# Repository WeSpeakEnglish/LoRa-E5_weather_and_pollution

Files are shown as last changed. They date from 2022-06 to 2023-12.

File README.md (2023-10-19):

# This PolluTAG based on LoRa E5 mini modules from seed.
It is custom FW, so you need to erase the STM32 chip first [Erase Factory AT Firmware](https://wiki.seeedstudio.com/LoRa_E5_mini/#21-erase-factory-at-firmware), you may need to retrieve and save the Device EUI before erasing of the Factory AT Firmware before we program with SDK

# Sensors for this custom build
1. SHT40 for humidity and temperature over I2C2 
2. ZE27-O3 Ozone sensor over USART2
3. SN-GCJA5 PM sensor over I2C2 

## Whole PRJ is ready to compile in CubeIDE
*LoRa-E5_weather_and_pollution.ioc* is configuration file for CubeMX
*decoder.js* - is decoder for payload for datacake - just copy this JS code into decoder section

### It is sending the payload over LoRaWAN appx. every 2.5 mins
Usually it takes up to 10 min. to react on downlink command (depend of communication stability)

### Downlink port #2
Encoder for downlink (measurements.LED_ON is interface fild on datacake):
```javascript 
function Encoder(measurements, port) {
    if(measurements.LED_ON.value) return [1];
    else return [0];
}
```

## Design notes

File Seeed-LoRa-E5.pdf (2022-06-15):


18/03/2022

Seeed-LoRa-E5 Project
Configuration Report

## 1. Description

### 1.1. Project

Project Name | Seeed-LoRa-E5
Board Name | custom
Generated with: | STM32CubeMX 6.5.0
Date | 03/18/2022

### 1.2. MCU

MCU Series | STM32WL
MCU Line | STM32WLEx
MCU name | STM32WLE5JCIx
MCU Package | UFBGA73
MCU Pin number | 73

### 1.3. Core(s) information

Core(s) | ARM Cortex-M4

## 2. Pinout Configuration

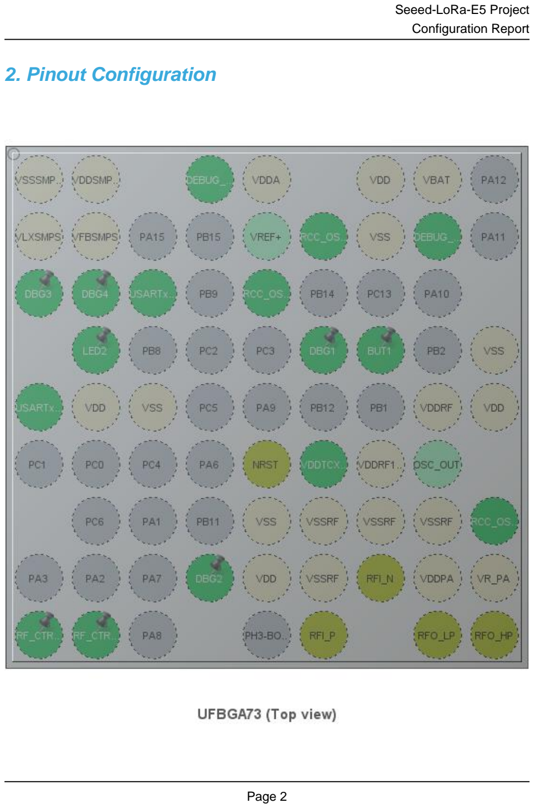
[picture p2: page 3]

## 3. Pins Configuration

Pin Number UFBGA73 | Pin Name (function after reset) | Pin Type | Alternate Function(s) | Label
A1 | VSSSMPS | Power
A2 | VDDSMPS | Power
A4 | PA14 | I/O | DEBUG_JTCK-SWCLK
A5 | VDDA | Power
A7 | VDD | Power
A8 | VBAT | Power
B1 | VLXSMPS | Power
B2 | VFBSMPS | Power
B6 | PC14-OSC32_IN | I/O | RCC_OSC32_IN
B7 | VSS | Power
B8 | PA13 | I/O | DEBUG_JTMS-SWDIO
C1 | PB3 * | I/O | GPIO_Output | DBG3
C2 | PB4 * | I/O | GPIO_Output | DBG4
C3 | PB7 | I/O | USART1_RX | USARTx_RX
C5 | PC15-OSC32_OUT | I/O | RCC_OSC32_OUT
D2 | PB5 * | I/O | GPIO_Output | LED2
D6 | PA0 * | I/O | GPIO_Output | DBG1
D7 | PB13 | I/O | GPIO_EXTI13 | BUT1
D9 | VSS | Power
E1 | PB6 | I/O | USART1_TX | USARTx_TX
E2 | VDD | Power
E3 | VSS | Power
E8 | VDDRF | Power
E9 | VDD | Power
F5 | NRST | Reset
F6 | PB0-VDD_TCXO | I/O | VDDTCXO
F7 | VDDRF1V55 | Power
G5 | VSS | Power
G6 | VSSRF | Power
G7 | VSSRF | Power
G8 | VSSRF | Power
G9 | OSC_IN | MonoIO | RCC_OSC_IN
H4 | PB10 * | I/O | GPIO_Output | DBG2
H5 | VDD | Power
H6 | VSSRF | Power
H7 | RFI_N | MonoIO

Pin Number UFBGA73 | Pin Name (function after reset) | Pin Type | Alternate Function(s) | Label
H8 | VDDPA | Power
H9 | VR_PA | Power
J1 | PA4 * | I/O | GPIO_Output | RF_CTRL1
J2 | PA5 * | I/O | GPIO_Output | RF_CTRL2
J6 | RFI_P | MonoIO
J8 | RFO_LP | MonoIO
J9 | RFO_HP | MonoIO

* The pin is affected with an I/O function

## 4. Clock Tree Configuration

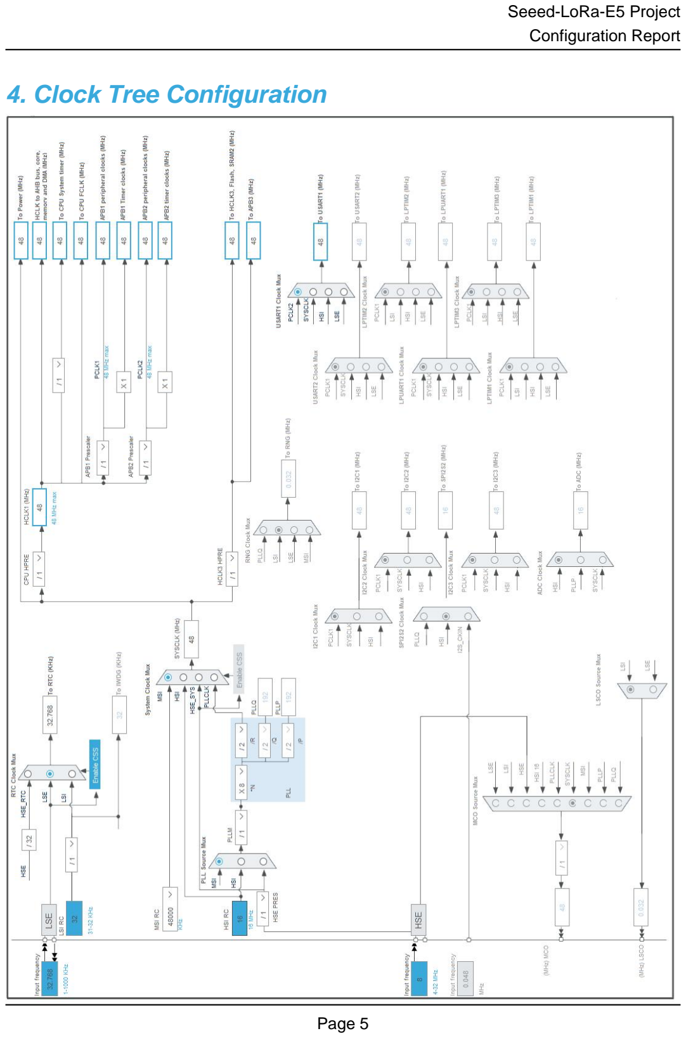
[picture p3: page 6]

## 5. Software Project

### 5.1. Project Settings

Name | Value
Project Name | Seeed-LoRa-E5
Project Folder | C:\Users\danam\STM32CubeIDE\workspace_1.7.0\Seeed-LoRa-E5
Toolchain / IDE | STM32CubeIDE
Firmware Package Name and Version | STM32Cube FW_WL V1.2.0
Application Structure | Advanced
Generate Under Root | Yes
Do not generate the main() | No
Minimum Heap Size | 0x200
Minimum Stack Size | 0x400

### 5.2. Code Generation Settings

Name | Value
STM32Cube MCU packages and embedded software | Copy only the necessary library files
Generate peripheral initialization as a pair of '.c/.h' files | Yes
Backup previously generated files when re-generating | Yes
Keep User Code when re-generating | Yes
Delete previously generated files when not re-generated | Yes
Set all free pins as analog (to optimize the power consumption) | No
Enable Full Assert | No

### 5.3. Advanced Settings - Generated Function Calls

Rank | Function Name | Peripheral Instance Name
1 | SystemClock_Config | RCC
2 | MX_GPIO_Init | GPIO
3 | MX_ADC_Init | ADC
4 | MX_RTC_Init | RTC
5 | MX_DMA_Init | DMA
6 | MX_USART1_UART_Init | USART1
7 | MX_SUBGHZ_Init | SUBGHZ
8 | MX_LoRaWAN_Init | LORAWAN

## 6. Power Consumption Calculator report

### 6.1. Microcontroller Selection

Series | STM32WL
Line | STM32WLEx
MCU | STM32WLE5JCIx
Datasheet | DS13105_Rev7

### 6.2. Parameter Selection

Temperature | 25
Vdd | 3.0

### 6.3. Battery Selection

Battery | Li-SOCL2(AAA700)
Capacity | 700.0 mAh
Self Discharge | 0.08 %/month
Nominal Voltage | 3.6 V
Max Cont Current | 10.0 mA
Max Pulse Current | 30.0 mA
Cells in series | 1
Cells in parallel | 1

### 6.4. Sequence

Step | Step1 | Step2
Mode | RUN | STOP2
Vdd | 3.0 | 3.0
Voltage Source | Battery | Battery
Range | Range1-Medium/SMPS-OFF | NoRange
Fetch Type | SRAM1 | NA
CPU Frequency | 48 MHz | 0 Hz
Clock Configuration | MSI | ALL_CLOCKS_OFF
Clock Source Frequency | 48 MHz | 0 Hz
Peripherals
Additional Cons. | 0 mA | 0 mA
Average Current | 5.65 mA | 885 nA
Duration | 0.1 ms | 0.9 ms
DMIPS | 60.0 | 0.0
Ta Max | 124.47 | 125
Category | In DS Table | In DS Table

### 6.5. Results

Sequence Time | 1 ms | Average Current | 565.8 µA
Battery Life | 1 month, 21 days, 1 hour | Average DMIPS | 60.0 DMIPS

### 6.6. Chart

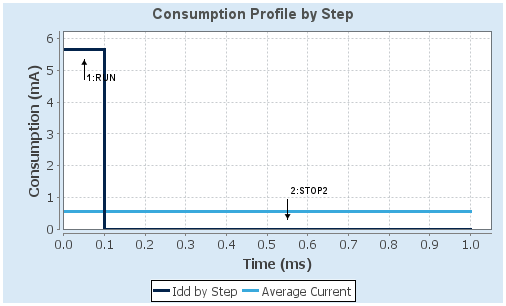
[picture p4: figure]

## 7. Peripherals and Middlewares Configuration

### 7.1. ADC

mode: Temperature Sensor Channel
mode: Vrefint Channel
7.1.1. Parameter Settings:

ADC_Settings:
Clock Prescaler | Synchronous clock mode divided by 4 *
Resolution | ADC 12-bit resolution
Calibration | Disable
Data Alignment | Right alignment
Scan Conversion Mode | Disabled
End Of Conversion Selection | End of single conversion
Low Power Auto Wait | Disabled
Auto Off | Disabled
Continuous Conversion Mode | Disabled
Discontinuous Conversion Mode | Disabled
External Trigger Conversion Source | Regular Conversion launched by software
External Trigger Conversion Edge | None
DMA Continuous Requests | Disabled
Overrun behaviour | Overrun data overwritten *
Sequencer | Sequencer set to fully configurable
SamplingTime Common 1 | 160.5 Cycles *
SamplingTime Common 2 | 160.5 Cycles *
Oversampling Mode | Disabled
Trigger Frequency | High frequency
ADC_Regular_ConversionMode:
Enable Regular Conversions | Disable

### 7.2. ADV_TRACE

mode: Enabled

### 7.3. DEBUG

JTAG and Trace: Serial Wire

### 7.4. MISC

mode: misc

### 7.5. RCC

High Speed Clock (HSE): TCXO
Low Speed Clock (LSE) : Crystal/Ceramic Resonator
7.5.1. Parameter Settings:

System Parameters:

VDD voltage (V) | 3.3
Instruction Cache | Enabled
Prefetch Buffer | Disabled
Data Cache | Enabled
Flash Latency(WS) | 2 WS (3 CPU cycle)
RCC Parameters:
HSI Calibration Value | 64
MSI Calibration Value | 0
MSI Auto Calibration | Enabled
HSE Startup Timout Value (ms) | 100
LSE Startup Timout Value (ms) | 5000
LSE Drive Capability | LSE oscillator low drive capability
Power Parameters:
Power Regulator Voltage Scale | Power Regulator Voltage Scale 1

### 7.6. RTC

mode: Activate Clock Source
mode: Activate Calendar
Alarm A: Internal Alarm A
7.6.1. Parameter Settings:

General:

Asynchronous Predivider value | RTC_PREDIV_A *
Bin Mode | Free running Binary mode *
SSRU Underflow Interrupt | Enabled
Alarm A:
Free running 32 bit value | 0
Binary AutoControl | RTC_ALARMSUBSECONDBIN_AUTOCLR_NO *
Free running 32 bit mask | SS[31:0] are compared and must match to activate alarm.

### 7.7. SEQUENCER

mode: Enabled

### 7.8. SUBGHZ

mode: Activated
7.8.1. Parameter Settings:
Baudrate Prescaler Value | 4 *

### 7.9. SYS

Timebase Source: None

### 7.10. TIMER

mode: Enabled

### 7.11. TINY_LPM

mode: Enabled

### 7.12. USART1

Mode: Asynchronous
7.12.1. Parameter Settings:

Basic Parameters:

Baud Rate | 115200
Word Length | 8 Bits (including Parity)
Parity | None
Stop Bits | 1
Advanced Parameters:
Data Direction | Receive and Transmit
Over Sampling | 16 Samples
Single Sample | Disable
ClockPrescaler | 1
Fifo Mode | Enable *
Txfifo Threshold | 1 eighth full configuration

Rxfifo Threshold | 1 eighth full configuration
Advanced Features:
Auto Baudrate | Disable
TX Pin Active Level Inversion | Disable
RX Pin Active Level Inversion | Disable
Data Inversion | Disable
TX and RX Pins Swapping | Disable
Overrun | Enable
DMA on RX Error | Enable
MSB First | Disable

### 7.13. LORAWAN

mode: Enabled
7.13.1. LoRaWAN application:

Application selection:
Application | End Node skeleton *
Application configuration recommandations | !! Please read carefully Information panel below!!

board settings:

Send Tx on Timer or Button Evt | TX_ON_TIMER
Probes Lines in Platform Settings | true *
lora_app:
Active region | LORAMAC_REGION_US915 *
Transmition duty cycle | 10000
Application user port | 2
Switch class port | 3
Default class | CLASS_A
Default handler message state | Unconfirmed message
Handler Adaptive Data Rate | On
Default activation type | OTAA
Force rejoin at each reboot | true
Default Unicast ping slots periodicity | 4
Default reponse timeout for class b and class c confirmed downlink frames in milli seconds. | 8000
sys_conf:
Trace verbose level | VLEVEL_M
Enable Application Logging | true
Disable Low Power Mode | false
Enable Sensor | false

7.13.2. LoRaWAN commissioning:

Commissioning:

Public network | true
Current network ID | 0
se-identity:
Static Device EUI | true *
LoRaWAN device EUI | 2C, F7, F1, 20, 24, 90, 0E, A5 *
App/Join EUI | 01, 01, 01, 01, 01, 01, 01, 01
Application key | 8B,0C,9A,82,E6,74,A5,11,B9,E 5,26,A9,11,87,EB,84 *
Network key | 8B,0C,9A,82,E6,74,A5,11,B9,E 5,26,A9,11,87,EB,84 *
Static Device Address | false
Network session key | 2B,7E,15,16,28,AE,D2,A6,AB,F7,15,88,0 9,CF,4F,3C
Application session key | 2B,7E,15,16,28,AE,D2,A6,AB,F7,15,88,0 9,CF,4F,3C

lorawan_conf:

Enable Key read access | true
7.13.3. LoRaWAN middleware:

lorawan_conf:

Region(s) selection | please select the desired region(s) in the list below
Region Asia freq: 923 | false
Region Australia freq: 915 | false
Region China freq: 470 | false
Region China freq: 779 | false
Region Europe freq: 433 | false
Region Europe freq: 868 | true
Region Korea freq: 920 | false
Region India freq: 865 | false
Region USA freq: 915 | true
Region Russia freq: 864 | false
Enable Hybrid mode | true *
Enable LoRaMAC ClassB | false
Enable the context management storage | false
Select the LoRaWAN Link Layer specification version | v1.0.3

radio_conf:

Radio maximum wakeup time (in ms) | 1
radio_board_if:
Select radio Driver | Bsp via extSettings *
mw_log_conf:
Enable Middleware log | true
7.13.4. Platform Settings:
ADC | ADC
RTC | RTC
USART | USART1
Debug Line 1 | PA0
Debug Line 2 | PB10
Debug Line 3 | PB3
Debug Line 4 | PB4

* User modified value

## 8. System Configuration

### 8.1. GPIO configuration

IP | Pin | Signal | GPIO mode | GPIO pull/up pull down | Max Speed | User Label
DEBUG | PA14 | DEBUG_JTCK-SWCLK | n/a | n/a | n/a
| PA13 | DEBUG_JTMS-SWDIO | n/a | n/a | n/a
RCC | PC14-OSC32_IN | RCC_OSC32_IN | n/a | n/a | n/a
| PC15-OSC32_OU T | RCC_OSC32_O UT | n/a | n/a | n/a
| PB0-VDD_TCXO | VDDTCXO | n/a | n/a | n/a
| OSC_IN | RCC_OSC_IN | n/a | n/a | n/a
USART1 | PB7 | USART1_RX | Alternate Function Push Pull | No pull-up and no pull-down | Very High * | USARTx_RX
| PB6 | USART1_TX | Alternate Function Push Pull | No pull-up and no pull-down | Very High * | USARTx_TX
| | | | | * | DBG3
| PB4 | GPIO_Output | Output Push Pull | No pull-up and no pull-down | Very High * | DBG4
| PB5 | GPIO_Output | Output Push Pull | No pull-up and no pull-down | Very High * | LED2
| PA0 | GPIO_Output | Output Push Pull | No pull-up and no pull-down | Very High * | DBG1
| PB13 | GPIO_EXTI13 | External Interrupt Mode with Falling edge trigger detection | Pull-up * | n/a | BUT1
| PB10 | GPIO_Output | Output Push Pull | No pull-up and no pull-down | Very High * | DBG2
| PA4 | GPIO_Output | Output Push Pull | No pull-up and no pull-down | Very High * | RF_CTRL1
| PA5 | GPIO_Output | Output Push Pull | No pull-up and no pull-down | Very High * | RF_CTRL2
GPIO | PB3 | GPIO_Output | Output Push Pull | No pull-up and no pull-down | Very High

### 8.2. DMA configuration

DMA request | Stream | Direction | Priority
USART1_TX | DMA1_Channel1 | Memory To Peripheral | Low

USART1_TX: DMA1_Channel1 DMA request Settings:

Mode: | Normal
Peripheral Increment: | Disable
Memory Increment: | Enable *
Peripheral Data Width: | Byte
Memory Data Width: | Byte

### 8.3. NVIC configuration

8.3.1. NVIC
Interrupt Table | Enable | Preenmption Priority | SubPriority
Non maskable interrupt | true | 0 | 0
Hard fault interrupt | true | 0 | 0
Memory management fault | true | 0 | 0
Prefetch fault, memory access fault | true | 0 | 0
Undefined instruction or illegal state | true | 0 | 0
System service call via SWI instruction | true | 0 | 0
Debug monitor | true | 0 | 0
Pendable request for system service | true | 0 | 0
System tick timer | true | 0 | 0
RTC Tamper, RTC TimeStamp, LSECSS and RTC SSRU Interrupts | true | 0 | 0
DMA1 Channel 1 Interrupt | true | 2 | 0
USART1 Interrupt | true | 2 | 0
EXTI Lines [15:10] Interrupt | true | 0 | 0
RTC Alarms (A and B) Interrupt | true | 0 | 0
SUBGHZ Radio Interrupt | true | 0 | 0
PVD and PVM detector | | unused
FLASH (CFI) global Interrupt | | unused
RCC Interrupt | | unused
ADC Interrupt | | unused
8.3.2. NVIC Code generation

Enabled interrupt Table Select for init sequence ordering

| | Generate IRQ
| | handler | Call HAL handler
Non maskable interrupt | false | true | false
Hard fault interrupt | false | true | false
Memory management fault | false | true | false
Prefetch fault, memory access fault | false | true | false
Undefined instruction or illegal state | false | true | false
System service call via SWI instruction | false | true | false
Debug monitor | false | true | false
Pendable request for system service | false | true | false
System tick timer | false | true | false
RTC Tamper, RTC TimeStamp, LSECSS and RTC SSRU Interrupts | false | true | true
DMA1 Channel 1 Interrupt | false | true | true
USART1 Interrupt | false | true | true

Enabled interrupt Table | Select for init sequence ordering | Generate IRQ handler | Call HAL handler
EXTI Lines [15:10] Interrupt | false | true | true
RTC Alarms (A and B) Interrupt | false | true | true
SUBGHZ Radio Interrupt | false | true | true

* User modified value

## 9. System Views

9.1. Category view
9.1.1. Current

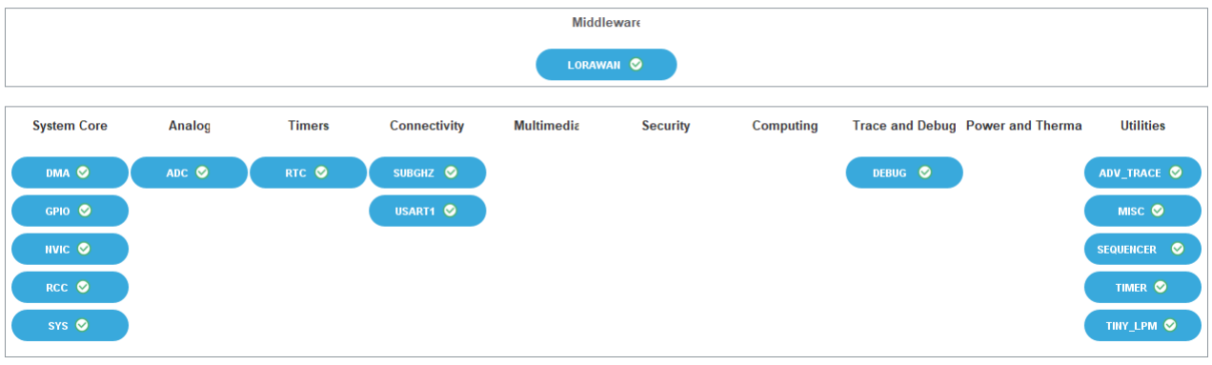
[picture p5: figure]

## 10. Docs & Resources

Type | Link
Presentations | https://www.st.com/resource/en/product_presentation/stm32-stm8_embedded_software_solutions.pdf
Presentations | https://www.st.com/resource/en/product_presentation/stm32_eval-tools_portfolio.pdf
Presentations | https://www.st.com/resource/en/product_presentation/stm32_stm8_functi onal-safety-packages.pdf
Presentations | https://www.st.com/resource/en/product_presentation/stm32-stm8_software_development_tools.pdf
Presentations | https://www.st.com/resource/en/product_presentation/microcontrollers_stm32wl_series_product_overview.pdf
Presentations | https://www.st.com/resource/en/product_presentation/stm32cubemonitor-wireless-longrange_rftest.pdf
Flyers | https://www.st.com/resource/en/flyer/flnucleolrwan.pdf
Flyers | https://www.st.com/resource/en/flyer/flstm32nucleo.pdf
Flyers | https://www.st.com/resource/en/flyer/flstm32wl.pdf
Flyers | https://www.st.com/resource/en/flyer/flstm32wbvl.pdf
Application Notes | https://www.st.com/resource/en/application_note/an1181-electrostatic-discharge-sensitivity-measurement-stmicroelectronics.pdf
Application Notes | https://www.st.com/resource/en/application_note/an1709-emc-design-guide-for-stm8-stm32-and-legacy-mcus-stmicroelectronics.pdf
Application Notes | https://www.st.com/resource/en/application_note/an2606-stm32-microcontroller-system-memory-boot-mode-stmicroelectronics.pdf
Application Notes | https://www.st.com/resource/en/application_note/an2639-soldering-recommendations-and-package-information-for-leadfree-ecopack-mcus-and-mpus-stmicroelectronics.pdf
Application Notes | https://www.st.com/resource/en/application_note/an2834-how-to-get-the-best-adc-accuracy-in-stm32-microcontrollers-stmicroelectronics.pdf
Application Notes | https://www.st.com/resource/en/application_note/an2867-oscillator-design-guide-for-stm8afals-stm32-mcus-and-mpus-stmicroelectronics.pdf

Application Notes | https://www.st.com/resource/en/application_note/an3126-audio-and-waveform-generation-using-the-dac-in-stm32-products-stmicroelectronics.pdf
Application Notes | https://www.st.com/resource/en/application_note/an3155-usart-protocol-used-in-the-stm32-bootloader-stmicroelectronics.pdf
Application Notes | https://www.st.com/resource/en/application_note/an4013-stm32-crossseries-timer-overview-stmicroelectronics.pdf
Application Notes | https://www.st.com/resource/en/application_note/an4229-how-to-implement-a-vocoder-solution-using-stm32-microcontrollers-stmicroelectronics.pdf
Application Notes | https://www.st.com/resource/en/application_note/an4286-spi-protocol-used-in-the-stm32-bootloader-stmicroelectronics.pdf
Application Notes | https://www.st.com/resource/en/application_note/an4655-virtually-increasing-the-number-of-serial-communication-peripherals-in-stm32-applications-stmicroelectronics.p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
Application Notes | https://www.st.com/resource/en/application_note/an4750-handling-of-soft-errors-in-stm32-applications-stmicroelectronics.pdf
Application Notes | https://www.st.com/resource/en/application_note/an4759-using-the-hardware-realtime-clock-rtc-and-the-tamper-management-unit-tamp-with-stm32-microcontrollers-stmicroe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
Application Notes | https://www.st.com/resource/en/application_note/an4776-generalpurpose-timer-cookbook-for-stm32-microcontrollers-stmicroelectronics.pdf
Application Notes | https://www.st.com/resource/en/application_note/an4803-highspeed-si-simulations-using-ibis-and-boardlevel-simulations-using-hyperlynx-si-on-stm32-mcus-and-mpus-stmic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
Application Notes | https://www.st.com/resource/en/application_note/an4894-eeprom-emulation-techniques-and-software-for-stm32-microcontrollers-stmicroelectronics.pdf
Application Notes | https://www.st.com/resource/en/application_note/an5027-interfacing-pdm-digital-microphones-using-stm32-mcus-and-mpus-stmicroelectronics.pdf
Application Notes | https://www.st.com/resource/en/application_note/an5036-thermal-management-guidelines-for-stm32-applications-stmicroelectronics.pdf
Application Notes | https://www.st.com/resource/en/application_note/an5042-precise-hse-

| frequency-and-startup-time-tuning-for-stm32-wireless-mcus-stmicroelectronics.pdf
Application Notes | https://www.st.com/resource/en/application_note/an5156-introduction-to-stm32-microcontrollers-security-stmicroelectronics.pdf
Application Notes | https://www.st.com/resource/en/application_note/an5225-usb-typec-power-delivery-using-stm32-mcus-and-mpus-stmicroelectronics.pdf
Application Notes | https://www.st.com/resource/en/application_note/an5406-how-to-build-a-lora-application-with-stm32cubewl-stmicroelectronics.pdf
Application Notes | https://www.st.com/resource/en/application_note/an5407-optimized-rf-board-layout-for-stm32wl-series-stmicroelectronics.pdf
Application Notes | https://www.st.com/resource/en/application_note/an5408-migrating-from-stm32l0-stm32l1-and-stm32l4-series-associated-with-sx12xx-transceivers-to-stm32wl-series-microc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
Application Notes | https://www.st.com/resource/en/application_note/an5409-stm32cube-mcu-package-examples-for-stm32wl-series-stmicroelectronics.pdf
Application Notes | https://www.st.com/resource/en/application_note/an5457-rf-matching-network-design-guide-for-stm32wl-series-stmicroelectronics.pdf
Application Notes | https://www.st.com/resource/en/application_note/an5480-how-to-build-a-sigfox-application-with-stm32cubewl-stmicroelectronics.pdf
Application Notes | https://www.st.com/resource/en/application_note/an5543-enhanced-methods-to-handle-spi-communication-on-stm32-devices-stmicroelectronics.pdf
Application Notes | https://www.st.com/resource/en/application_note/an5568-ultralowpower-features-of-stm32wl-series-microcontrollers-stmicroelectronics.pdf
Application Notes | https://www.st.com/resource/en/application_note/an4899-stm32-microcontroller-gpio-configuration-for-hardware-settings-and-lowpower-consumption-stmicroelectronics.pdf
Application Notes | https://www.st.com/resource/en/application_note/an5690-vrefbuf-peripheral-applications-and-trimming-technique-stmicroelectronics.pdf
Application Notes | https://www.st.com/resource/en/application_note/an5664-rssi-and-snr-for-lora-modulation-on-stm32wl-series-stmicroelectronics.pdf

Application Notes
for related Tools

https://www.st.com/resource/en/application_note/an1202_freertos_guidefreertos-guide-stmicroelectronics.pdf

& Software
Application Notes for related Tools & Software | https://www.st.com/resource/en/application_note/an1602_semihosting_in_truestudio-how-to-do-semihosting-in-truestudio-stmicroelectronics.pdf
Application Notes for related Tools & Software | https://www.st.com/resource/en/application_note/an1801_stm32cubeprogrammer_in_truestudio-installing-stm32cubeprogrammer-in-truestudio-stmicroelectronics.pdf
Application Notes for related Tools & Software | https://www.st.com/resource/en/application_note/atollic_editing_keyboard_shortcuts-atollic-editing-keyboard-shortcuts-stmicroelectronics.pdf
Application Notes for related Tools & Software | https://www.st.com/resource/en/application_note/iar_to_atollic_truestudio_migration_guide-truestudio-for-arm-migration-guide-iar-embedded-workbench-to-truestudio-stm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
Application Notes for related Tools & Software | https://www.st.com/resource/en/application_note/stm32cubemx_installation_in_truestudio-stm32cubemx-installation-in-truestudio-stmicroelectronics.pdf
Application Notes for related Tools & Software | https://www.st.com/resource/en/application_note/an4502-stm32-smbuspmbus-embedded-software-expansion-for-stm32cube-stmicroelectronics.pdf
Application Notes for related Tools & Software | https://www.st.com/resource/en/application_note/an4657-stm32-inapplication-programming-iap-using-the-usart-stmicroelectronics.pdf
Application Notes for related Tools & Software | https://www.st.com/resource/en/application_note/an4759-using-the-hardware-realtime-clock-rtc-and-the-tamper-management-unit-tamp-with-stm32-microcontrollers-stmicroe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
Application Notes for related Tools & Software | https://www.st.com/resource/en/application_note/an4841-digital-signal-processing-for-stm32-microcontrollers-using-cmsis-stmicroelectronics.pdf
Application Notes for related Tools & Software | https://www.st.com/resource/en/application_note/an4894-eeprom-emulation-techniques-and-software-for-stm32-microcontrollers-stmicroelectronics.pdf
Application Notes for related Tools & Software | https://www.st.com/resource/en/application_note/an5042-precise-hse-frequency-and-startup-time-tuning-for-stm32-wireless-mcus-stmicroelectronics.pdf

Application Notes for related Tools & Software | https://www.st.com/resource/en/application_note/an5054-secure-programming-using-stm32cubeprogrammer-stmicroelectronics.pdf
Application Notes for related Tools & Software | https://www.st.com/resource/en/application_note/an5360-getting-started-with-projects-based-on-the-stm32mp1-series-in-stm32cubeide-stmicroelectronics.pdf
Application Notes for related Tools & Software | https://www.st.com/resource/en/application_note/an5361-getting-started-with-projects-based-on-dualcore-stm32h7-microcontrollers-in-stm32cubeide-stmicroelectronics.pd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
Application Notes for related Tools & Software | https://www.st.com/resource/en/application_note/an5394-getting-started-with-projects-based-on-the-stm32l5-series-in-stm32cubeide-stmicroelectronics.pdf
Application Notes for related Tools & Software | https://www.st.com/resource/en/application_note/an5406-how-to-build-a-lora-application-with-stm32cubewl-stmicroelectronics.pdf
Application Notes for related Tools & Software | https://www.st.com/resource/en/application_note/an5409-stm32cube-mcu-package-examples-for-stm32wl-series-stmicroelectronics.pdf
Application Notes for related Tools & Software | https://www.st.com/resource/en/application_note/an5418-how-to-build-a-simple-usbpd-sink-application-with-stm32cubemx-stmicroelectronics.pdf
Application Notes for related Tools & Software | https://www.st.com/resource/en/application_note/an5426-migrating-graphics-middleware-projects-from-stm32cubemx-540-to-stm32cubemx-550-stmicroelectronics.pdf
Application Notes for related Tools & Software | https://www.st.com/resource/en/application_note/an5480-how-to-build-a-sigfox-application-with-stm32cubewl-stmicroelectronics.pdf
Application Notes for related Tools & Software | https://www.st.com/resource/en/application_note/an5481-lorawan-at-commands-for-stm32cubewl-stmicroelectronics.pdf
Application Notes for related Tools & Software | https://www.st.com/resource/en/application_note/an5544-integration-guide-of-sbsfu-on-stm32cubewl-including-kms-stmicroelectronics.pdf
Application Notes | https://www.st.com/resource/en/application_note/an5554-lorawan-

for related Tools & Software | firmware-update-over-the-air-with-stm32cubewl-stmicroelectronics.pdf
Application Notes for related Tools & Software | https://www.st.com/resource/en/application_note/an5564-getting-started-with-projects-based-on-dualcore-stm32wl-microcontrollers-in-stm32cubeide-stmicroelectronics.pd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
Application Notes for related Tools & Software | https://www.st.com/resource/en/application_note/an5566-rf-certification-process-for-nucleowl55jc-stmicroelectronics.pdf
Application Notes for related Tools & Software | https://www.st.com/resource/en/application_note/an5682-how-to-secure-lorawan-and-sigfox-with-stm32cubewl-stmicroelectronics.pdf
Application Notes for related Tools & Software | https://www.st.com/resource/en/application_note/an5687-longpacket-operation-with-stm32cubewl-stmicroelectronics.pdf
Application Notes for related Tools & Software | https://www.st.com/resource/en/application_note/an5731-stm32cubemx-and-stm32cubeide-threadsafe-solution-stmicroelectronics.pdf
Errata Sheets | https://www.st.com/resource/en/errata_sheet/es0506-stm32wle5xx-stm32wle4xx-device-errata-stmicroelectronics.pdf
Datasheet | https://www.st.com/resource/en/datasheet/dm00648230.pdf
Programming Manuals | https://www.st.com/resource/en/programming_manual/pm0214-stm32-cortexm4-mcus-and-mpus-programming-manual-stmicroelectronics.pdf
Programming Manuals | https://www.st.com/resource/en/programming_manual/pm0223-cortexm0-programming-manual-for-stm32l0-stm32g0-stm32wl-and-stm32wb-series-stmicroelectronics.pdf
Reference Manuals | https://www.st.com/resource/en/reference_manual/rm0461-stm32wlex-advanced-armbased-32bit-mcus-with-subghz-radio-solution-stmicroelectronics.pdf
Technical Notes & Articles | https://www.st.com/resource/en/technical_note/tn1163-description-of-wlcsp-for-microcontrollers-and-recommendations-for-its-use-stmicroelectronics.pdf
Technical Notes & Articles | https://www.st.com/resource/en/technical_note/tn1204-tape-and-reel-shipping-media-for-stm32-microcontrollers-in-bga-packages-stmicroelectronics.pdf

Technical Notes & Articles | https://www.st.com/resource/en/technical_note/tn1205-tape-and-reel-shipping-media-for-stm8-and-stm32-microcontrollers-in-fpn-packages-stmicroelectronics.pdf
Technical Notes & Articles | https://www.st.com/resource/en/technical_note/tn1206-tape-and-reel-shipping-media-for-stm8-and-stm32-microcontrollers-in-qfp-packages-stmicroelectronics.pdf
Technical Notes & Articles | https://www.st.com/resource/en/technical_note/tn1207-tape-and-reel-shipping-media-for-stm8-and-stm32-microcontrollers-in-so-packages-stmicroelectronics.pdf
Technical Notes & Articles | https://www.st.com/resource/en/technical_note/tn1208-tape-and-reel-shipping-media-for-stm8-and-stm32-microcontrollers-in-tssop-and-ssop-packages-stmicroelectronics.p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

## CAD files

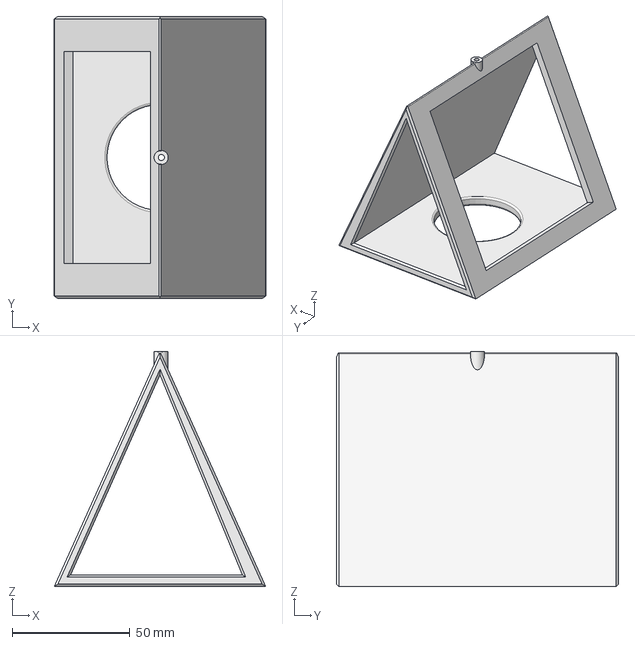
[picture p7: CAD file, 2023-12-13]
CASE_FREECAD/eternal.FCStd
90.0 x 120.0 x 100.0 mm

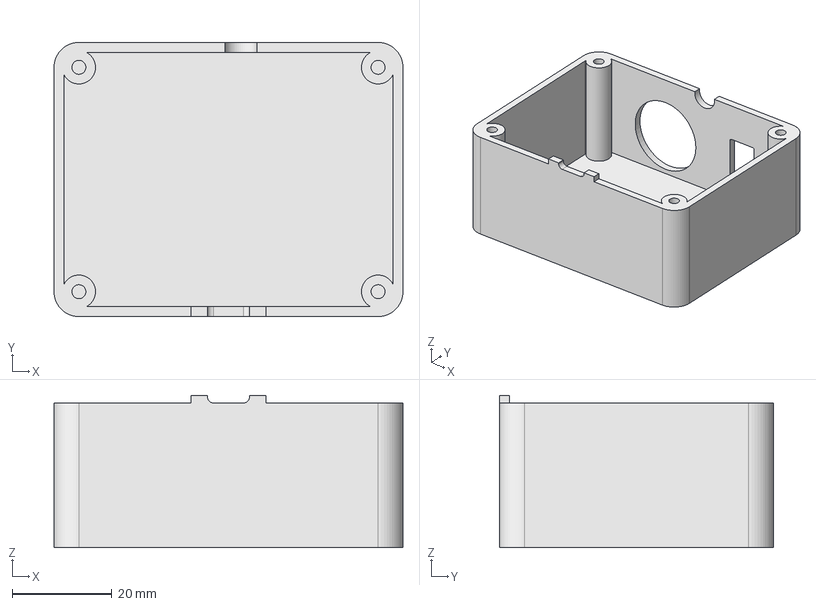
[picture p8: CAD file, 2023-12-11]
CASE_FREECAD/case.FCStd
70.0 x 55.0 x 30.5 mm

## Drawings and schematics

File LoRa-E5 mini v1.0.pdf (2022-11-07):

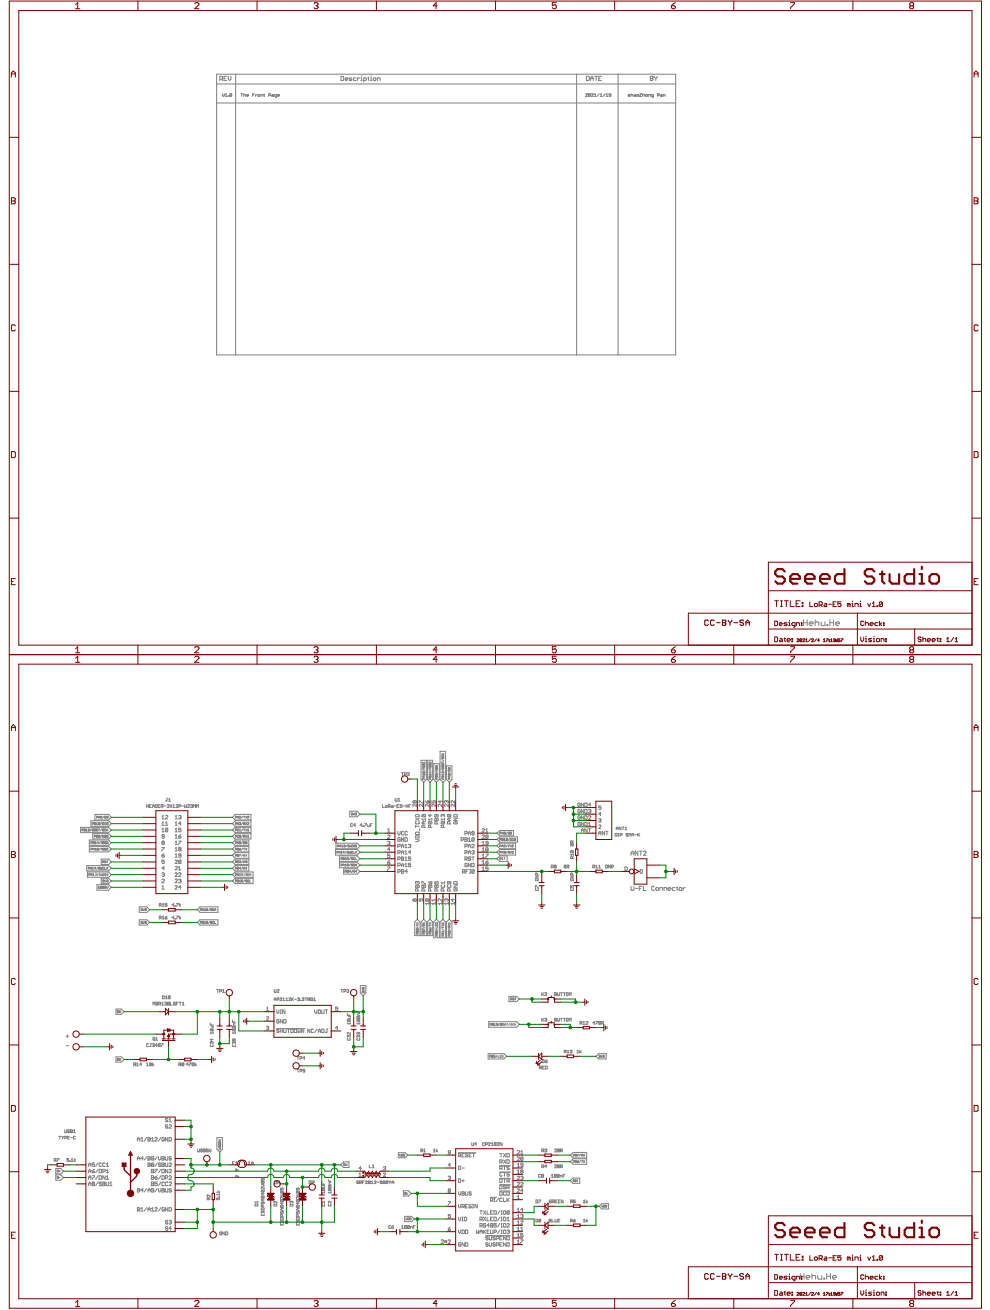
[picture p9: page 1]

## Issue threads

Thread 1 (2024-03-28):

NO DOWLINK ON THE SENSOR with ADR=On when DR is not SF12

pierre-microlide, 2024-03-28:
Hi,
i use Wio-E5 mini board with LoraWan app. All is ok with my gateway to join or read datas from sensor.
But, if i use the ADR=On to save power, when SF is less than 12, downlink are not received by the sensor ? The downlink is sent by the gateway.
I don't understand why ? Please, can you help me ?
Thanks
Regards
Pierre

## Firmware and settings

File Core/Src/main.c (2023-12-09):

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
/* Includes ------------------------------------------------------------------*/
#include "main.h"
#include "i2c.h"
#include "app_lorawan.h"
#include "lptim.h"
#include "spi.h"
#include "usart.h"
#include "gpio.h"

/* USER CODE BEGIN Includes */

#include "ZE27_O3.h"
/* USER CODE END Includes */


/* USER CODE BEGIN PV */

volatile uint8_t aRXBufferUser[ZE27_RX_BUFFER_SIZE];

uint8_t receivedFlag = 1;
uint32_t PM2_5;
uint32_t PM1;
uint32_t PM10;
uint16_t OzonePPB;
uint8_t extBattery;
float temp;
float humidity;
uint8_t PM_measure_flag = 1;
volatile int counter = 0;
uint8_t pmSensStatus = 0x00;

const uint8_t SHT40_cmd = 0xFD;
const uint8_t SHT40_addr = 0x44;
volatile uint8_t SHT40_dataRX[6] = {0,0,0,0,0,0};
uint16_t temp_hword; // teporarly temperature half word
uint16_t th_hword;   // teporarly humidy half  word

const uint8_t J5_SSP_addr = 0x33;
const uint8_t J5_SSP_cmd_status = 0x26;
volatile uint8_t J5_SSP_dataRX[12]= {0,0,0,0,0,0,0,0,0,0,0,0};

/* USER CODE END PV */

void SystemClock_Config(void);
/* USER CODE BEGIN 0 */
void MeasurePM_sens(void);
void MeasureOzone(void);
/* USER CODE END 0 */

/**
  * @brief  The application entry point.
  * @retval int
  */
int main(void)
{
  /* MCU Configuration--------------------------------------------------------*/

  /* Reset of all peripherals, Initializes the Flash interface and the Systick. */
  HAL_Init();

  /* Configure the system clock */
  SystemClock_Config();

  /* Initialize all configured peripherals */
  MX_GPIO_Init();
  MX_LoRaWAN_Init();
  MX_USART2_UART_Init();
  MX_I2C2_Init();
  MX_SPI2_Init();
  MX_LPTIM1_Init();
  /* USER CODE BEGIN 2 */

  F1_QueueIni(); // init Function queue
  F2_QueueIni();
  /* USER CODE END 2 */

  /* Infinite loop */
  /* USER CODE BEGIN WHILE */
  HAL_GPIO_WritePin(GPIOA, GPIO_PIN_9, GPIO_PIN_RESET);
  //HAL_TIM_Base_Start_IT(&htim16);
  HAL_LPTIM_TimeOut_Start_IT(&hlptim1,  256, 0);


  while (1)
  {

    /* USER CODE END WHILE */
    MX_LoRaWAN_Process();

    /* USER CODE BEGIN 3 */

    F1_pull()();
    F2_pull()();

  }


  /* USER CODE END 3 */
}

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
/* USER CODE BEGIN 4 */

void EnablePM_sens(void){
	HAL_GPIO_WritePin(GPIOA, GPIO_PIN_9, GPIO_PIN_SET);
}

void DisablePM_sens(void){
	HAL_GPIO_WritePin(GPIOA, GPIO_PIN_9, GPIO_PIN_RESET);
}

void MeasurePM_sens(void){
	HAL_I2C_Mem_Read(&hi2c2, J5_SSP_addr << 1, 0x00, 1, J5_SSP_dataRX, 12, 1000);
	HAL_I2C_Mem_Read(&hi2c2, J5_SSP_addr << 1, 0x26, 1, &pmSensStatus, 1, 1000);
 if(!pmSensStatus){
	PM1 = J5_SSP_dataRX[0] + (J5_SSP_dataRX[1] << 8) + (J5_SSP_dataRX[2] << 16) +  (J5_SSP_dataRX[3] << 24);
	PM2_5 = J5_SSP_dataRX[4] + (J5_SSP_dataRX[5] << 8) + (J5_SSP_dataRX[6] << 16) +  (J5_SSP_dataRX[7] << 24);
	PM10 = J5_SSP_dataRX[8] + (J5_SSP_dataRX[9] << 8) + (J5_SSP_dataRX[10] << 16) +  (J5_SSP_dataRX[11] << 24);
 }
}
void MeasureOzone(void){
	uint16_t RxLen;
	HAL_UART_Receive_IT(&huart2, (uint8_t *) aRXBufferUser, ZE27_RX_BUFFER_SIZE);
	HAL_UARTEx_ReceiveToIdle(&huart2, (uint8_t *) aRXBufferUser, ZE27_RX_BUFFER_SIZE, &RxLen, 1000);
	OzonePPB = ZE27_parsePPB(aRXBufferUser);
}

void MeasureTempHum(void){

    HAL_I2C_Master_Receive(&hi2c2, (uint16_t)(SHT40_addr << 1),SHT40_dataRX, 6, 100);
    temp_hword = SHT40_dataRX[0] * 256 + SHT40_dataRX[1];
    th_hword = SHT40_dataRX[3] * 256 + SHT40_dataRX[4];
    temp  = -45.0 + 175.0 * (float)temp_hword/(float)65535.0;
    humidity = -6.0 + 125.0 * (float)th_hword/(float)65535.0;
    HAL_I2C_Master_Transmit(&hi2c2, (uint16_t)(SHT40_addr << 1),(uint8_t*)&SHT40_cmd, 1, 100);
}

#ifndef batTH
#define batTH 87
#endif

 void HAL_LPTIM_CompareMatchCallback(LPTIM_HandleTypeDef *hlptim)
{
	static char firstStart = 1;
   if (hlptim == &hlptim1)
   {

      switch(counter){
      case 10:
    	  if(firstStart)
    		  F1_push(EnablePM_sens);
    	  break;
      case 35:
    	  if(firstStart){
    		  F1_push(MeasureTempHum);
    		  F2_push(MeasureTempHum);
    	  }
    	  break;
      case 40:
    	  if(firstStart){
    		  F2_push(MeasureTempHum);
    		  F1_push(MeasurePM_sens);
    		  //F1_push(MeasureOzone);
    		  F1_push(DisablePM_sens);
    		  firstStart = 0;
    	  }
    	  break;
      case 859:
    	  if(extBattery > batTH)
    		  F1_push(EnablePM_sens);

    	  break;
      case 895:
    	  if(extBattery > batTH)
    	  F2_push(MeasureTempHum);
    	  break;
      case 896:
    	  //F1_push(MeasureTempHum);
    	  //F1_push(MeasureOzone);
    	  break;

      case 897:
    	  if(extBattery > batTH)
    	  F2_push(MeasurePM_sens);
    	  break;
      case 899:
    	  F1_push(DisablePM_sens);
      }
      counter++;
      if(counter % 20 == 8)HAL_GPIO_WritePin(LED2_GPIO_Port, LED2_Pin, GPIO_PIN_RESET);///DBG
      if(counter % 20 == 9)HAL_GPIO_WritePin(LED2_GPIO_Port, LED2_Pin, GPIO_PIN_SET);///DBG
      counter %= 900;
   }
}



/* USER CODE END 4 */
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


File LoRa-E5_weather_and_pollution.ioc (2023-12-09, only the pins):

Mcu.UserName=STM32WLE5JCIx
PA0.GPIO_Label=DBG1
PA0.Signal=GPIO_Output
PA10.Signal=SPI2_MOSI
PA13.Signal=DEBUG_JTMS-SWDIO
PA14.Signal=DEBUG_JTCK-SWCLK
PA15.Signal=I2C2_SDA
PA2.Signal=USART2_TX
PA3.Signal=USART2_RX
PA4.GPIO_Label=RF_CTRL1
PA4.Signal=GPIO_Output
PA5.GPIO_Label=RF_CTRL2
PA5.Signal=GPIO_Output
PA9.GPIO_Label=CONNECT_PM_SENSOR
PA9.Signal=GPIO_Output
PB0-VDD_TCXO.Signal=VDDTCXO
PB10.GPIO_Label=SPI_CEN
PB10.Signal=GPIO_Output
PB13.Signal=SPI2_SCK
PB14.Signal=SPI2_MISO
PB15.Signal=I2C2_SCL
PB3.GPIO_Label=DBG3
PB3.Signal=GPIO_Output
PB4.Signal=ADC_IN3
PB5.GPIO_Label=LED2
PB5.Signal=GPIO_Output
PB6.GPIO_Label=USARTx_TX
PB6.Signal=USART1_TX
PB7.GPIO_Label=USARTx_RX
PB7.Signal=USART1_RX
PB9.GPIO_Label=SPI_CSN
PB9.Signal=GPIO_Output
PC14-OSC32_IN.Signal=RCC_OSC32_IN
PC15-OSC32_OUT.Signal=RCC_OSC32_OUT

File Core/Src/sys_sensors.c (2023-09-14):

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

/* Includes ------------------------------------------------------------------*/
#include "stdint.h"
#include "platform.h"
#include "sys_conf.h"
#include "sys_sensors.h"
#if defined (SENSOR_ENABLED) && (SENSOR_ENABLED == 0)
#include "adc_if.h"
#endif /* SENSOR_ENABLED */

/* USER CODE BEGIN Includes */
#if defined (SENSOR_ENABLED) && (SENSOR_ENABLED == 1)
#if defined (X_NUCLEO_IKS01A2)
#warning "IKS drivers are today available for several families but not stm32WL"
#warning "up to the user adapt IKS low layer to map it on WL board driver"
#warning "this code would work only if user provide necessary IKS and BSP layers"
#include "iks01a2_env_sensors.h"
#elif defined (X_NUCLEO_IKS01A3)
/*
## How to add IKS01A3 to CubeWL

 1. Download STM32CubeExpansion_MEMS1_V8.0.0
 2. Copy Drivers From `STM32CubeExpansion_MEMS1_V8.0.0\Drivers\BSP\IKS01A3` to CubeWL `Drivers\BSP\IKS01A3` and add to the IDE Project
 3. Copy `STM32CubeExpansion_MEMS1_V8.0.0\Drivers\BSP\IKS01A3\iks01a3_conf_template.h` into `Projects\NUCLEO-WL55JC\Applications\LoRaWAN\End_Node\LoRaWAN\Target\iks01a3_conf.h`.
 4. Copy files nucleo_l476rg_bus.c/nucleo_l476rg_bus.h  from `STM32L476RG-Nucleo\Applications\IKS01A3\ActiveTime\Inc and \Src` to `Projects\NUCLEO-WL55JC\Applications\LoRaWAN\End_Node\LoRaWAN\Target` and rename to `nucleo_wl55jc_bus.c` and `nucleo_wl55jc_bus.h` respectively
 5. Update `nucleo_wl55jc_bus.c`  include files  to
 ```bash
#include "nucleo_wl55jc_bus.h"
#include "stm32wlxx_nucleo_errno.h"
#include "stm32wlxx_hal.h"
```

6. Update definitions in `nucleo_wl55jc_bus.h`(to be commented since already defined elsewhere)

 ```bash
//#define USE_HAL_SPI_REGISTER_CALLBACKS 0
//#define USE_HAL_I2C_REGISTER_CALLBACKS 0
```

7. copy following components and add them (.c and .h) into IDE Project

../../../../../../Drivers/BSP/Components/lsm6dso
../../../../../../Drivers/BSP/Components/lis2dw12
../../../../../../Drivers/BSP/Components/lis2mdl
../../../../../../Drivers/BSP/Components/hts221
../../../../../../Drivers/BSP/Components/lps22hh
../../../../../../Drivers/BSP/Components/stts751
../../../../../../Drivers/BSP/Components/Common

8. Enable #define HAL_I2C_MODULE_ENABLED in stm32_hal_conf.h
9. Add stm32wlxx_hal_i2c.c and stm32wlxx_hal_i2c_ex.c in the IDE Project
10. Update hi2c->Instance in `nucleo_wl55jc_bus.c` to

```bash
  hi2c->Instance = I2C2;
```

11. Update msp function in `nucleo_wl55jc_bus.c`

```bash
static void I2C2_MspInit(I2C_HandleTypeDef *i2cHandle)
{
  GPIO_InitTypeDef GPIO_InitStruct;

  GPIO_InitStruct.Pin = GPIO_PIN_11 | GPIO_PIN_12;
  GPIO_InitStruct.Mode = GPIO_MODE_AF_OD;
  GPIO_InitStruct.Pull = GPIO_PULLUP;
  GPIO_InitStruct.Speed = GPIO_SPEED_FREQ_VERY_HIGH;
  GPIO_InitStruct.Alternate = GPIO_AF4_I2C2;
  HAL_GPIO_Init(GPIOA, &GPIO_InitStruct);

  __HAL_RCC_I2C2_CLK_ENABLE();
}

static void I2C2_MspDeInit(I2C_HandleTypeDef *i2cHandle)
{
  __HAL_RCC_I2C2_CLK_DISABLE();

  HAL_GPIO_DeInit(GPIOA, GPIO_PIN_11 | GPIO_PIN_12);

}
```
12. Replace I2C1xx by MX_I2C2xx and i2c1 by i2c2 in `nucleo_wl55jc_bus.c`
13. Replace I2C1xx by MX_I2C2xx in `nucleo_wl55jc_bus.h`
*/
#warning "IKS drivers are today available for several families but not stm32WL, follow steps defined in sys_sensors.c"
#include "iks01a3_env_sensors.h"
#else  /* not X_IKS01xx */
#error "user to include its sensor drivers"
#endif  /* X_NUCLEO_IKS01xx */
#elif !defined (SENSOR_ENABLED)
#error SENSOR_ENABLED not defined
#endif  /* SENSOR_ENABLED */
/* USER CODE END Includes */

/* External variables ---------------------------------------------------------*/

/* USER CODE BEGIN PD */
#define STSOP_LATTITUDE           ((float) 43.618622 )  /*!< default latitude position */
#define STSOP_LONGITUDE           ((float) 7.051415  )  /*!< default longitude position */
#define MAX_GPS_POS               ((int32_t) 8388607 )  /*!< 2^23 - 1 */
#define HUMIDITY_DEFAULT_VAL      50.0f                 /*!< default humidity */
#define TEMPERATURE_DEFAULT_VAL   18.0f                 /*!< default temperature */
#define PRESSURE_DEFAULT_VAL      1000.0f               /*!< default pressure */
/* USER CODE END PD */


/* USER CODE BEGIN PV */
#if defined (SENSOR_ENABLED) && (SENSOR_ENABLED == 1)
#if defined (X_NUCLEO_IKS01A2)
#warning "IKS drivers are today available for several families but not stm32WL"
#warning "up to the user adapt IKS low layer to map it on WL board driver"
#warning "this code would work only if user provide necessary IKS and BSP layers"
IKS01A2_ENV_SENSOR_Capabilities_t EnvCapabilities;
#elif defined (X_NUCLEO_IKS01A3)
IKS01A3_ENV_SENSOR_Capabilities_t EnvCapabilities;
#else  /* not X_IKS01Ax */
#error "user to include its sensor drivers"
#endif  /* X_NUCLEO_IKS01 */
#elif !defined (SENSOR_ENABLED)
#error SENSOR_ENABLED not defined
#endif  /* SENSOR_ENABLED */
/* USER CODE END PV */

/* Exported functions --------------------------------------------------------*/
int32_t EnvSensors_Read(sensor_t *sensor_data)
{
  /* USER CODE BEGIN EnvSensors_Read */
  float HUMIDITY_Value = HUMIDITY_DEFAULT_VAL;
  float TEMPERATURE_Value = TEMPERATURE_DEFAULT_VAL;
  float PRESSURE_Value = PRESSURE_DEFAULT_VAL;

#if defined (SENSOR_ENABLED) && (SENSOR_ENABLED == 1)
#if (USE_IKS01A2_ENV_SENSOR_HTS221_0 == 1)
  IKS01A2_ENV_SENSOR_GetValue(HTS221_0, ENV_HUMIDITY, &HUMIDITY_Value);
  IKS01A2_ENV_SENSOR_GetValue(HTS221_0, ENV_TEMPERATURE, &TEMPERATURE_Value);
#endif /* USE_IKS01A2_ENV_SENSOR_HTS221_0 */
#if (USE_IKS01A2_ENV_SENSOR_LPS22HB_0 == 1)
  IKS01A2_ENV_SENSOR_GetValue(LPS22HB_0, ENV_PRESSURE, &PRESSURE_Value);
  IKS01A2_ENV_SENSOR_GetValue(LPS22HB_0, ENV_TEMPERATURE, &TEMPERATURE_Value);
#endif /* USE_IKS01A2_ENV_SENSOR_LPS22HB_0 */
#if (USE_IKS01A3_ENV_SENSOR_HTS221_0 == 1)
  IKS01A3_ENV_SENSOR_GetValue(IKS01A3_HTS221_0, ENV_HUMIDITY, &HUMIDITY_Value);
  IKS01A3_ENV_SENSOR_GetValue(IKS01A3_HTS221_0, ENV_TEMPERATURE, &TEMPERATURE_Value);
#endif /* USE_IKS01A3_ENV_SENSOR_HTS221_0 */
#if (USE_IKS01A3_ENV_SENSOR_LPS22HH_0 == 1)
  IKS01A3_ENV_SENSOR_GetValue(IKS01A3_LPS22HH_0, ENV_PRESSURE, &PRESSURE_Value);
  IKS01A3_ENV_SENSOR_GetValue(IKS01A3_LPS22HH_0, ENV_TEMPERATURE, &TEMPERATURE_Value);
#endif /* USE_IKS01A3_ENV_SENSOR_LPS22HH_0 */
#elif !defined (SENSOR_ENABLED)
#error SENSOR_ENABLED not defined
#endif  /* SENSOR_ENABLED */

  sensor_data->humidity    = HUMIDITY_Value;
  sensor_data->temperature = TEMPERATURE_Value;
  sensor_data->pressure    = PRESSURE_Value;

  sensor_data->latitude  = (int32_t)((STSOP_LATTITUDE  * MAX_GPS_POS) / 90);
  sensor_data->longitude = (int32_t)((STSOP_LONGITUDE  * MAX_GPS_POS) / 180);

  return 0;
  /* USER CODE END EnvSensors_Read */
}
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

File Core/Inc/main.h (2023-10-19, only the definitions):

#define RTC_N_PREDIV_S 10
#define RTC_PREDIV_S ((1<<RTC_N_PREDIV_S)-1)
#define RTC_PREDIV_A ((1<<(15-RTC_N_PREDIV_S))-1)
#define DBG3_Pin GPIO_PIN_3
#define DBG3_GPIO_Port GPIOB
#define USARTx_RX_Pin GPIO_PIN_7
#define USARTx_RX_GPIO_Port GPIOB
#define SPI_CSN_Pin GPIO_PIN_9
#define SPI_CSN_GPIO_Port GPIOB
#define LED2_Pin GPIO_PIN_5
#define LED2_GPIO_Port GPIOB
#define DBG1_Pin GPIO_PIN_0
#define DBG1_GPIO_Port GPIOA
#define USARTx_TX_Pin GPIO_PIN_6
#define USARTx_TX_GPIO_Port GPIOB
#define CONNECT_PM_SENSOR_Pin GPIO_PIN_9
#define CONNECT_PM_SENSOR_GPIO_Port GPIOA
#define SPI_CEN_Pin GPIO_PIN_10
#define SPI_CEN_GPIO_Port GPIOB
#define RF_CTRL1_Pin GPIO_PIN_4
#define RF_CTRL1_GPIO_Port GPIOA
#define RF_CTRL2_Pin GPIO_PIN_5
#define RF_CTRL2_GPIO_Port GPIOA

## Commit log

2022-06-19 uart dma
2022-07-19 migrated to newest Cube IDE version, added humidity and temp by SHT40 0x44 addr. sensor , decoder updated
2022-09-04 5min downlink reaction LED on port 2 tuned
2022-11-08 4 slots scan, test 30 min , every 70 sec ok
2022-11-08 *debug*added SPI NRF24L01 - stability need to be checked with better circumstancies
    [LoRa-E5_weather_and_pollution.ioc, lora_app.c, main.c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]
2023-07-21 uart to IT
2023-09-14 downgraded, sensor changed to SN-GCJA5
2023-09-15 tst blocking uart
2023-09-16 pm2.5 sensor works via i2c, decoder updated to 0.1 PM sensitivity
2023-09-17 ozone sensor added Z27O3
2023-09-17 ozone sensor added Z27O3, decoder updated to receive ozone
2023-10-19 lwered powerc
2023-10-19 lowered power consumption to 25mA
2023-10-26 LPM enabled, average current consumption 15 mA, mcu plus sensor 4.86mA
2023-10-27 upd 3d case
    [case-Body.stl, case.FCStd]
2023-10-29 LPM -> current reduced, lptim1 in use
    [Seeed-LoRa-E5 Debug.cfg]
2023-12-09 tested 1w some unstability
    tested 1w some unstability, probably due to power supply or LP timer, recovering automatically, power supply in sleep all dcdc activated 2 mA
2023-12-11 case updated
    [case-Body.stl, case.FCStd]
2023-12-12 case updated 2 stl files for print
2023-12-13 added external case
    [eternal.FCStd]

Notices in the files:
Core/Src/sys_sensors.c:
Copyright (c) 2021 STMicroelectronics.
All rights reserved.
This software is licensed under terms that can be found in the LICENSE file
